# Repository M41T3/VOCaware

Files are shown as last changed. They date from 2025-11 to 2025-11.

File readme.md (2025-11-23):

# What is VOCaware?

VOCaware is a small device that measures volatile organic components (VOCs) in the ambient air and indicates potential unhealthy exposure.

VOCs are released during 3D printing caused by the melting process of plastic filaments. The exposure depends on the material and the melting temperature. Since there are no long term studies on the implications of VOC exposure to the human being it‘s reasonable to mitigate the risk of  potential health issues by avoiding these gases.

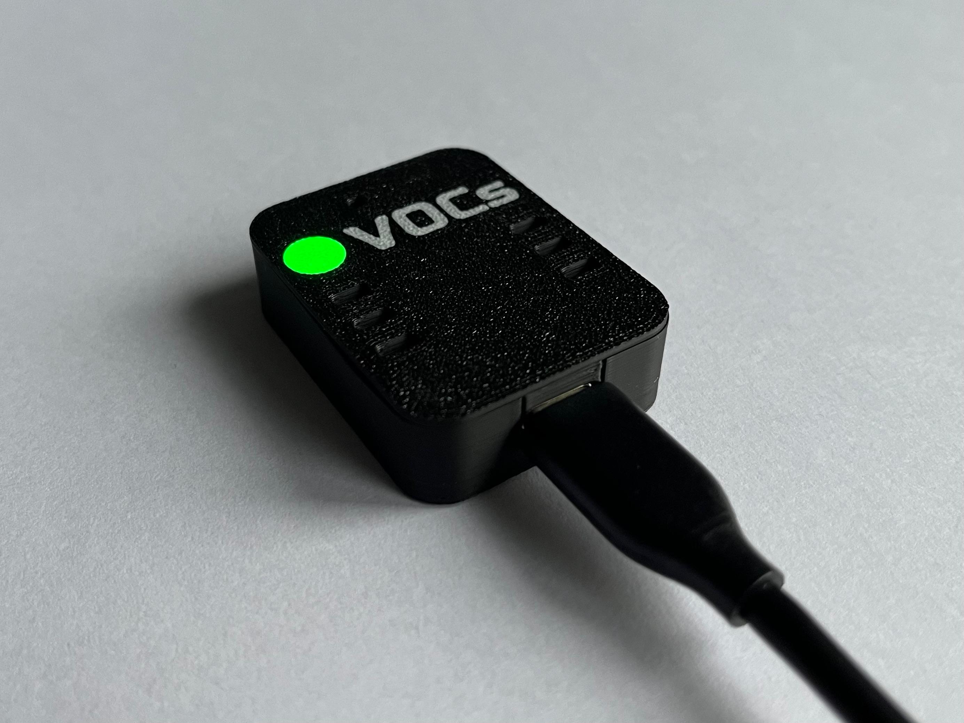
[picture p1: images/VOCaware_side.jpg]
VOCaware side view
  

# Features

- WIFI enabled microcontroller (ESP32-S3) to transmit sensor data wirelessly or via serial communication
- Sensirion SGP40 VOC sensor 
- Sensirion SHT40 temperature and humdity sensor to calibrate VOC sensor
- WS2812B LED to indicate intensity of exposure
- USB C plug to power and program device
- Compact PCB design (40 mm x 30 mm)
- Compact housing ( 43 mm x 33 mm x 11 mm) with magnets to easily attach to metal objects

# PCB

- 2 layers
- 40 x 30 mm
- JLCPCB production files available

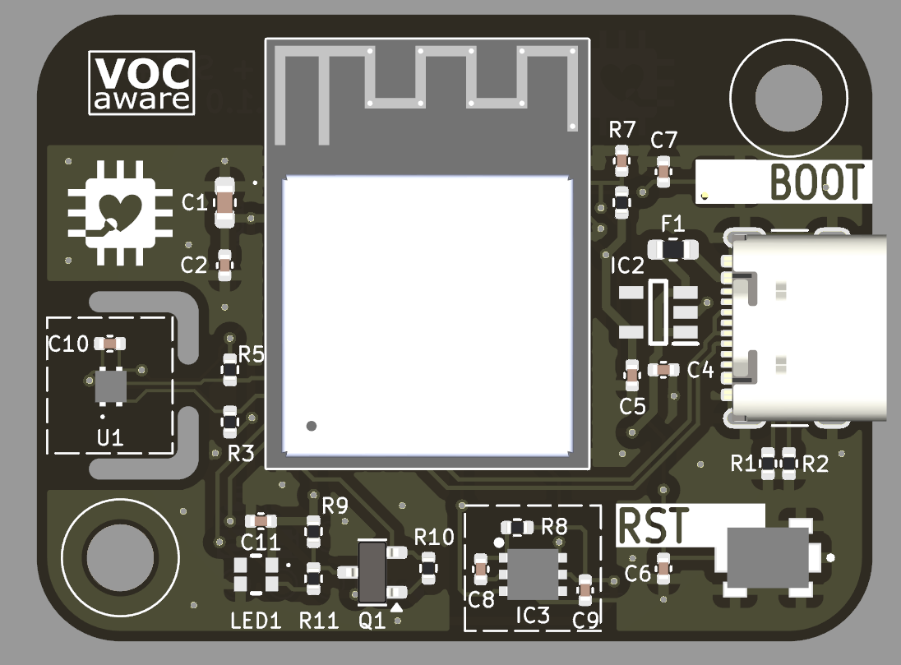
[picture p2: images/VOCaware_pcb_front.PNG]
VOCaware PCB front

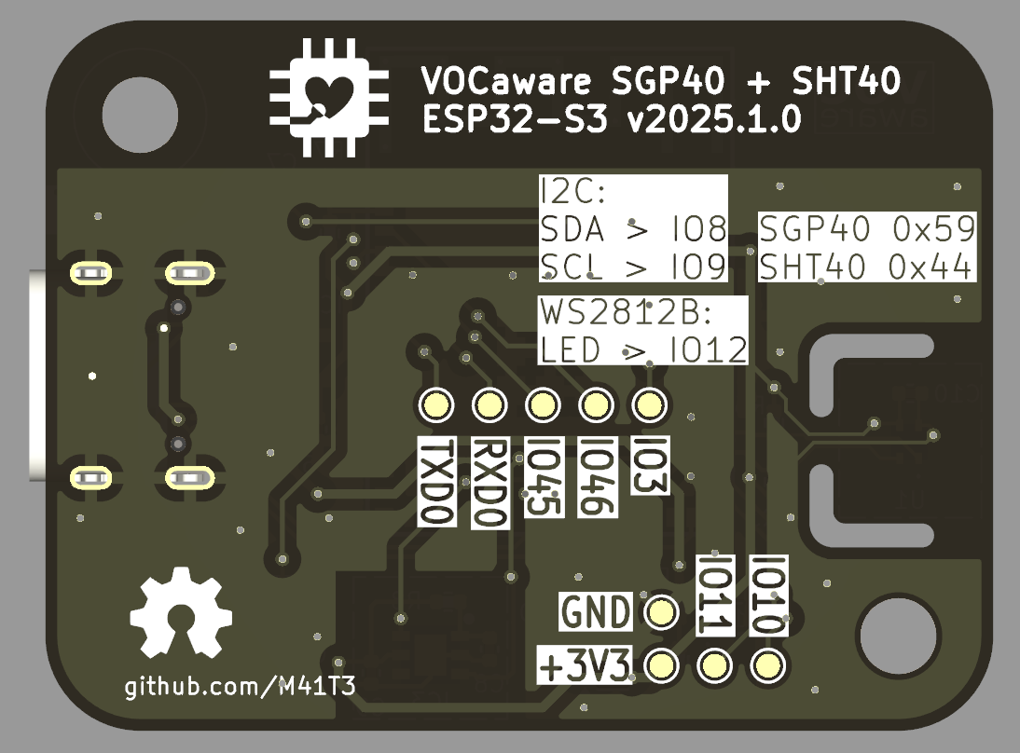
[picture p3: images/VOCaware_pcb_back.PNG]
VOCaware PCB front


# Housing

The lid simply clips to the bottom part of the housing. On the backside are holes for magnets.

Frontside:
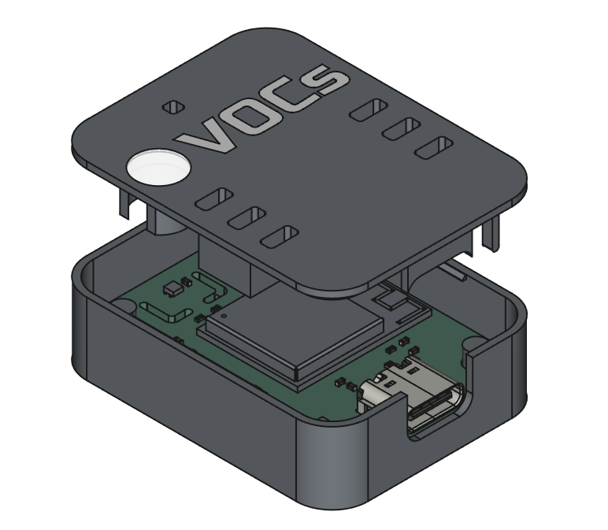
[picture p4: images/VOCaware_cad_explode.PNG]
VOCaware CAD1


Backside: 
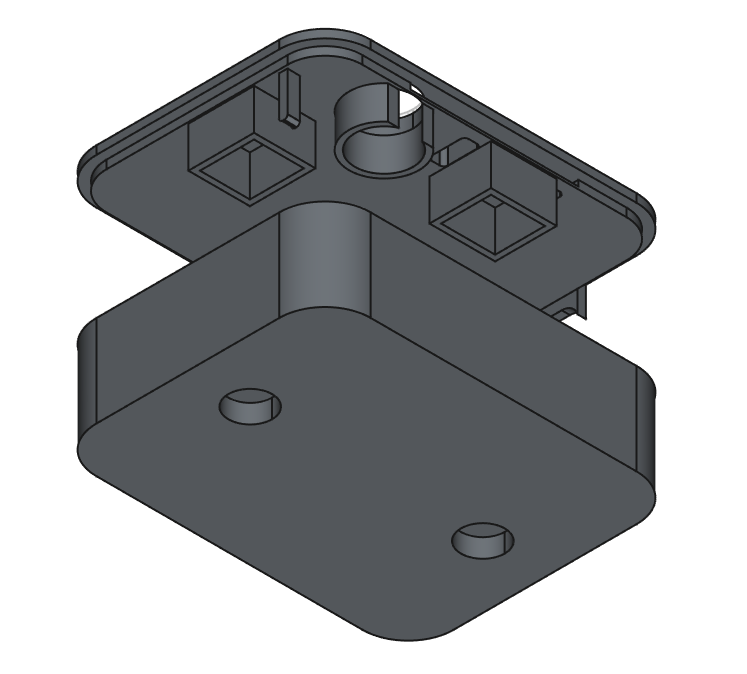
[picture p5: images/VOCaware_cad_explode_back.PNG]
VOCaware CAD2


# VOC Indication

Color code of the RGB LED is programmed according to Sensirions SGP40 VOC index scale to show a trend of the intensity over time. The devices needs severeal seconds to set up. During this, the LED blinks green.  

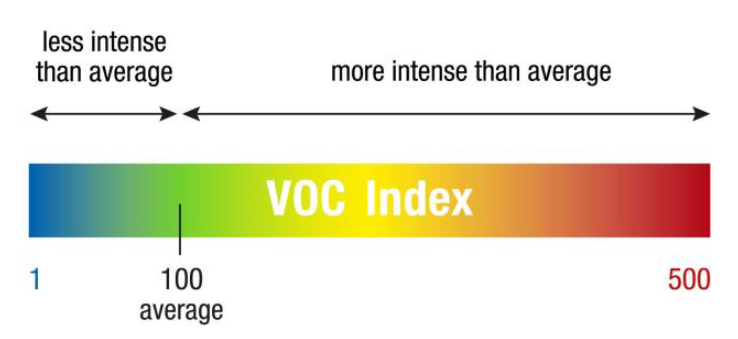
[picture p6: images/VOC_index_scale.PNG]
VOC Index Scale


| LED Color| VOC Index | Exposure |
|---|---|---|
| blue | 0 - 70  | decreased |
| green | 70 - 140 | OK |
| yellow | 131 - 210 | slightly increased |
| orange | 221 - 280 | increased |
| red | 281 - 350 | significantly increased |
| red blink  | 351 - 500 | concerningly increased  |

# Compatible to Bambu Lab P1S 3D Printer

Device fits in enclosure of the P1S printer and can be power directly from the internal USB plug. Please print the housing with PETG filament or similar so that it withstands the increased temperatures in the chamber.

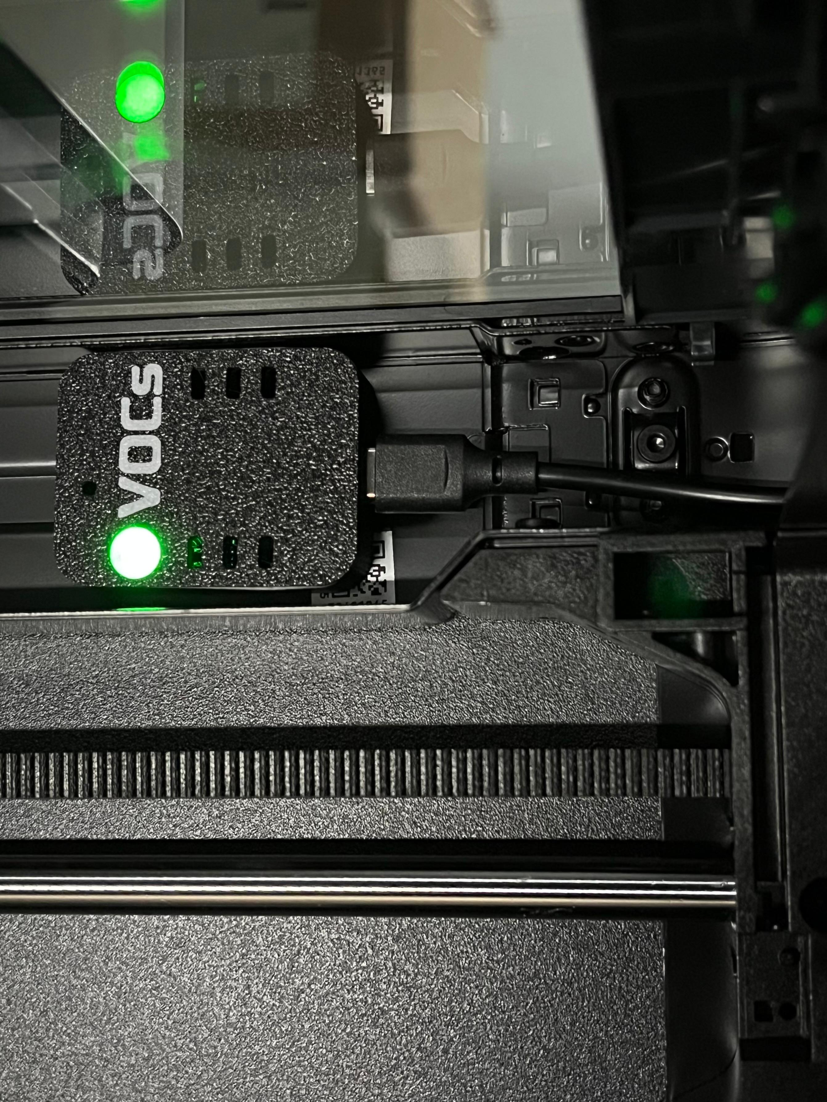
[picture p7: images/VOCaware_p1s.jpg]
VOCaware P1S

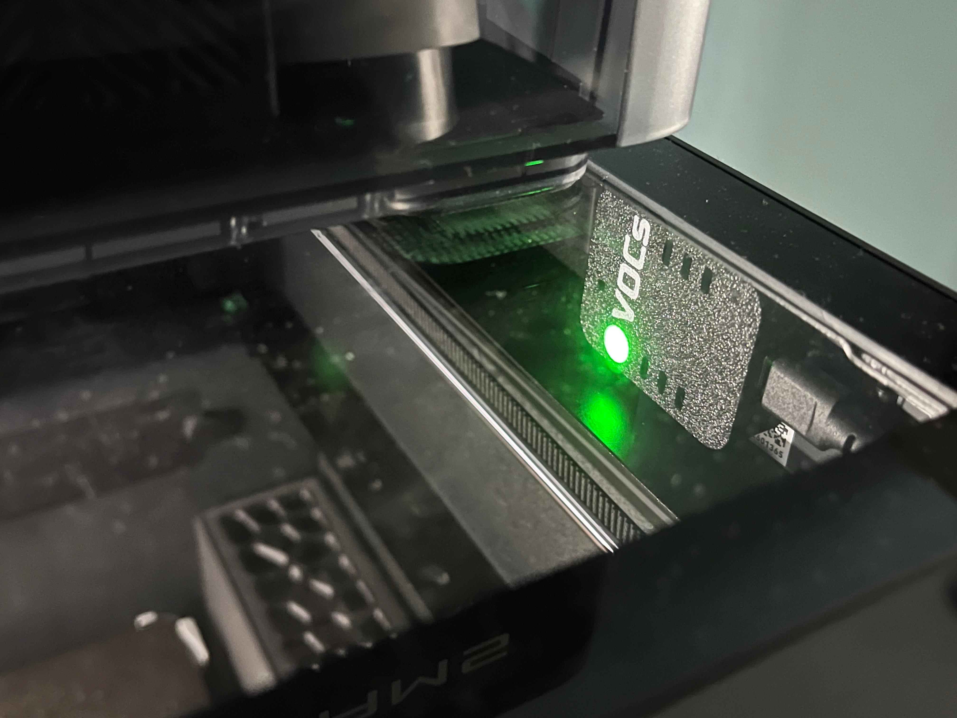
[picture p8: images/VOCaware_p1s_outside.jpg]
VOCaware P1S outside


The VOCaware is also visible in the camera view of the Bambu Studio interface:

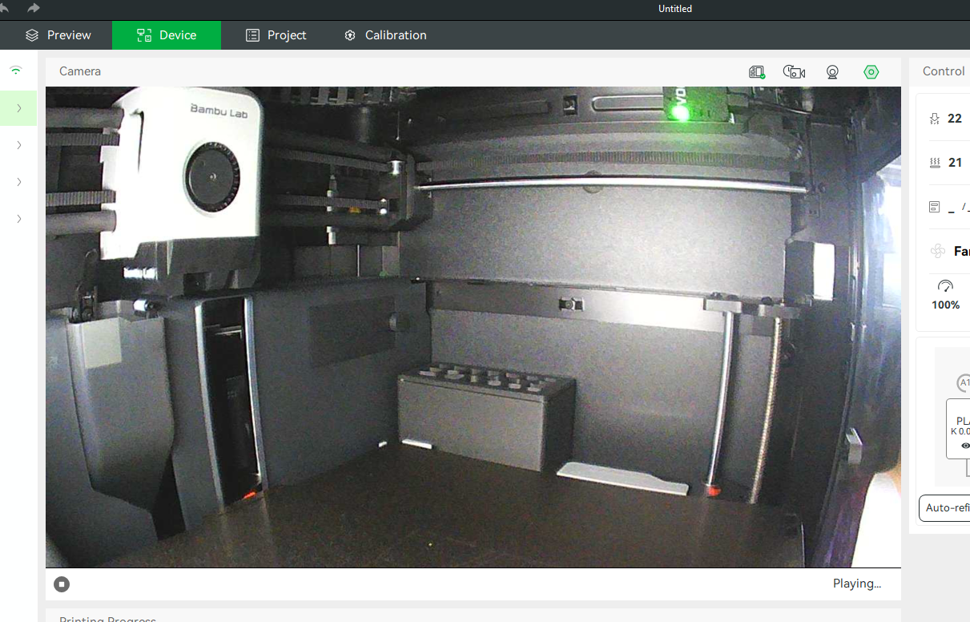
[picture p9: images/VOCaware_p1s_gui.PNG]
VOCaware P1S GUI


# What's Next
Ideas for improvements and features:

- Control Bento Box via VOCaware GPIO according to VOC Index
- Connect to MQTT Broker

# Known Issues

Unfortunatly the ground layer is not sufficiently interconnected. It can be easily fixed by soldering a short wire from the GND test pin to the ground zone as shown in the image:

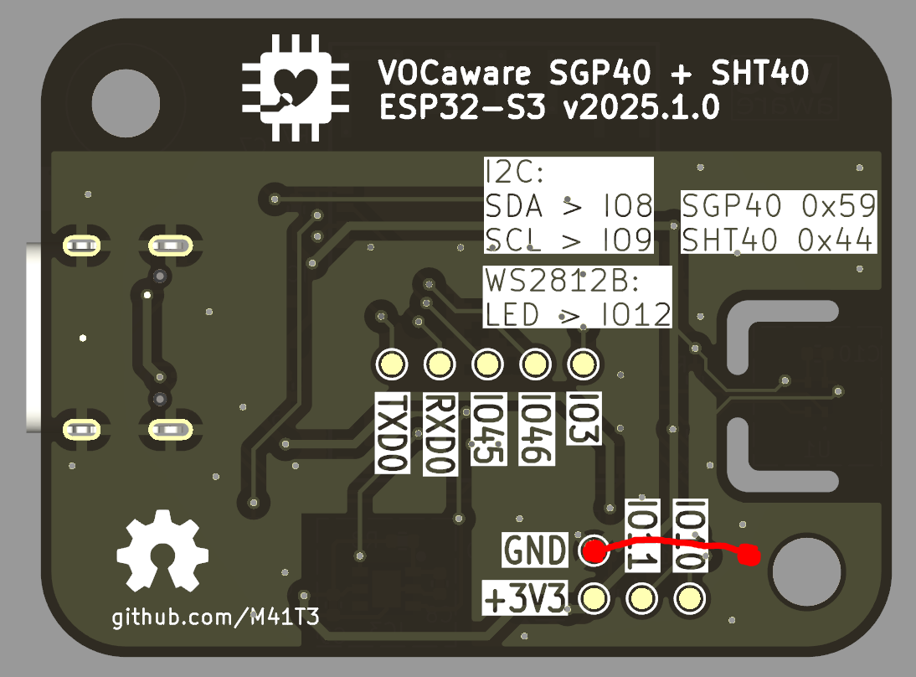
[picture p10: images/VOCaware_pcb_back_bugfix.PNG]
VOCaware ground layer


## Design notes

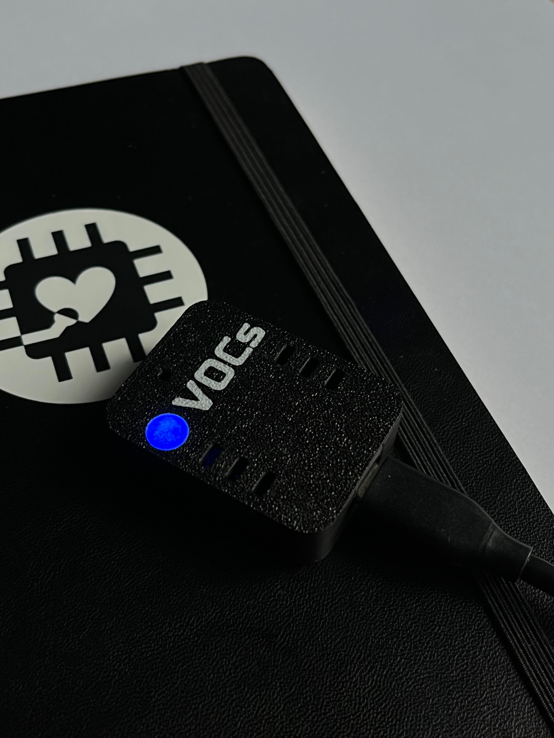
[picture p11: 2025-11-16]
images/VOCaware_blue.jpg

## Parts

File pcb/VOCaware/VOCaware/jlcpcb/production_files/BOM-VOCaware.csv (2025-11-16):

Comment | Designator | Footprint | LCSC | Quantity
BSS138BK | Q1 | SOT-23 | C112239 | 1
0.1uF | C10,C11,C2,C3,C6,C7 | C_0402_1005Metric | C1525 | 6
10uF | C4 | C_0402_1005Metric | C15525 | 1
USB_C_Receptacle_USB2.0_16P | J1 | USB_C_Receptacle_GCT_USB4105-xx-A_16P_TopMnt_Horizontal | C165948 | 1
SW_Push | SW1 | SolderJumper-2_P1.3mm_Open_Pad1.0x1.5mm | C221900 | 1
470 | R11 | R_0402_1005Metric | C25117 | 1
4.7 | R8 | R_0402_1005Metric | C25121 | 1
10k | R10,R7,R9 | R_0402_1005Metric | C25744 | 3
4.7k | R3,R5 | R_0402_1005Metric | C25900 | 2
5.1k 1% | R1,R2 | R_0402_1005Metric | C25905 | 2
SGP40-D-R4 | IC3 | SON80P244X244X95-7N | C2874215 | 1
ESP32-S3-MINI-1-N8 | IC1 | ESP32S3MINI1N8 | C2913206 | 1
XL-0807RGBC-WS2812B | LED1 | XL0807RGBCWS2812B | C3646929 | 1
AP2112K-3.3TRG1 | IC2 | SOT95P285X140-5N | C51118 | 1
1uF | C5,C8,C9 | C_0402_1005Metric | C52923 | 3
22uF | C1 | C_0603_1608Metric | C59461 | 1
SMD0603-050 | F1 | Fuse_0603_1608Metric | C69679 | 1
SHT40-AD1F-R2 | U1 | SHT40AD1FR2 | C7461846 | 1

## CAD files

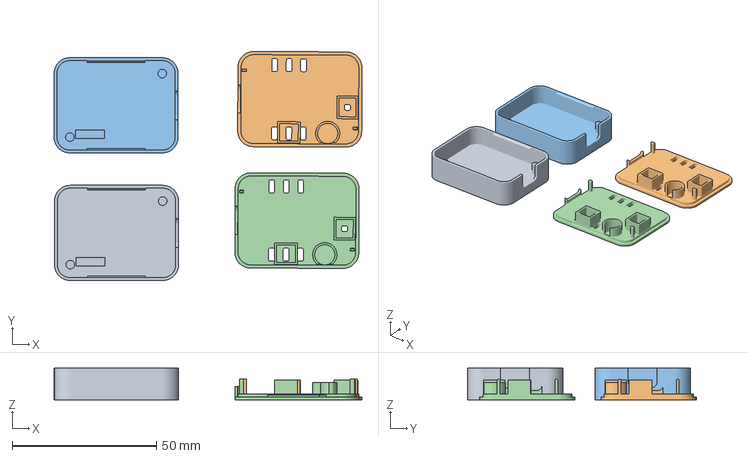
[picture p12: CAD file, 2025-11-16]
housing/VOCaware_housing_v1.3mf
106.7 x 79.3 x 11.0 mm
VOCaware_housing-housing_v1.step x 2
VOCaware_housing-lid_v1.step x 2

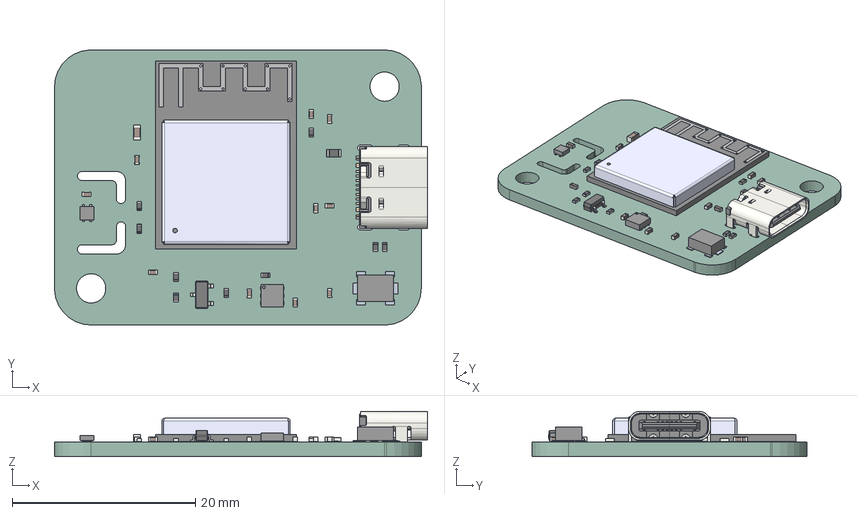
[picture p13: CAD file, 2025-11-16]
pcb/VOCaware/VOCaware/VOCaware.step
40.7 x 30.0 x 4.96 mm
C_0402_1005Metric x 10
R_0402_1005Metric x 9
SOT_23
ASSEMBLY x 3
C_0603_1608Metric
USB_C_Receptacle_16P_TopMnt_Horizontal_GCT_USB4105-xx-A
ESP32-S3-MINI-1-N8
Fuse_0603_1608Metric
VOCaware_PCB

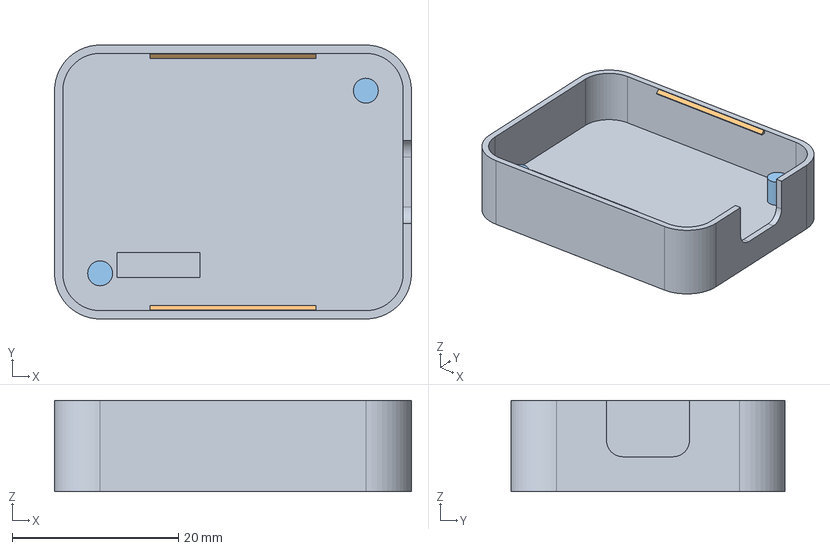
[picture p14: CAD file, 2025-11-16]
housing/VOCaware_housing-housing_v1.step
43.0 x 33.0 x 11.0 mm
housing_bottom
snap_bot_Chamfer
snap_top_Chamfer
m3_pole_tr
m3_pole_bl

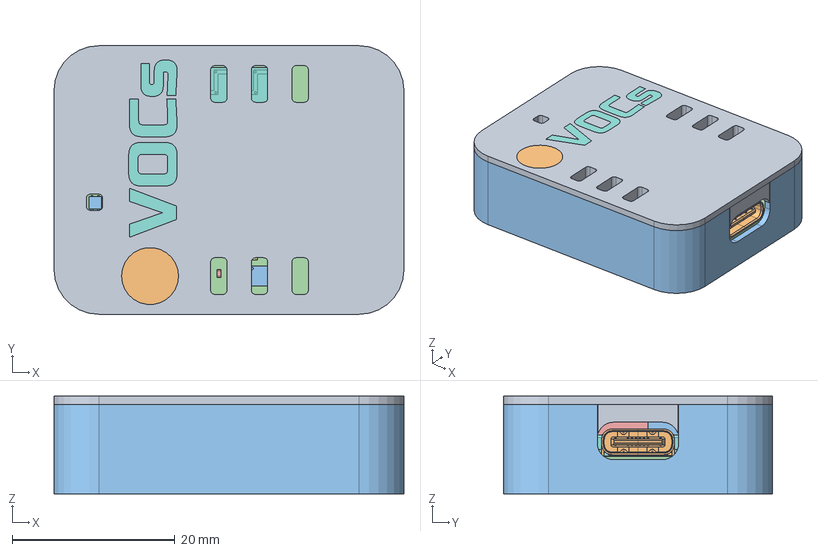
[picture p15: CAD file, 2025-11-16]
housing/VOCaware_housing.FCStd
43.0 x 33.0 x 12.0 mm
C_0402_1005Metric
C_0402_1005Metric002
R_0402_1005Metric
R_0402_1005Metric002
C_0402_1005Metric004
R_0402_1005Metric004
R_0402_1005Metric006
C_0402_1005Metric006
R_0402_1005Metric008
SOT_23
ASSEMBLY
R_0402_1005Metric010
C_0402_1005Metric008
C_0603_1608Metric
R_0402_1005Metric012
R_0402_1005Metric014
C_0402_1005Metric010
USB_C_Receptacle_16P_TopMnt_Horizontal_GCT_USB4105-xx-A
ASSEMBLY001
C_0402_1005Metric012
R_0402_1005Metric016
C_0402_1005Metric014
C_0402_1005Metric016
ESP32-S3-MINI-1-N8
C_0402_1005Metric018
Fuse_0603_1608Metric
ASSEMBLY002
VOCaware_PCB
m3_pole_bl
m3_pole_tr
snap_top_Chamfer
snap_bot_Chamfer
usb_top_cut
led_cirlcle_trans_extr
housing_bottom
sgp_separator_extr
sht_separator_extr
press_fit_tr_fillet
press_fit_bl_fillet
VOCs_text_extr_color
lid_text_cutout
led_sep_cutted

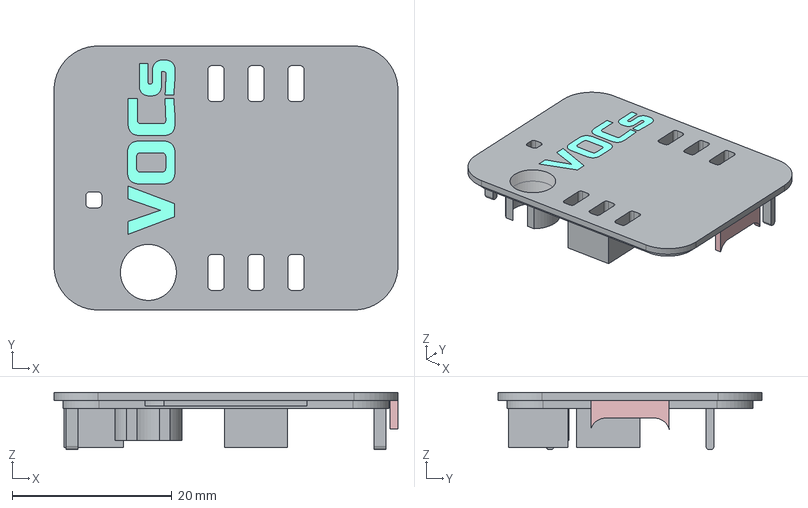
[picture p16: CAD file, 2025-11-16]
housing/VOCaware_housing-lid_v1.step
43.0 x 33.0 x 7.15 mm
led_sep_cutted
lid_text_cutout
VOCs_text_extr_color
press_fit_bl_fillet
press_fit_tr_fillet
sht_separator_extr
sgp_separator_extr
led_cirlcle_trans_extr
usb_top_cut

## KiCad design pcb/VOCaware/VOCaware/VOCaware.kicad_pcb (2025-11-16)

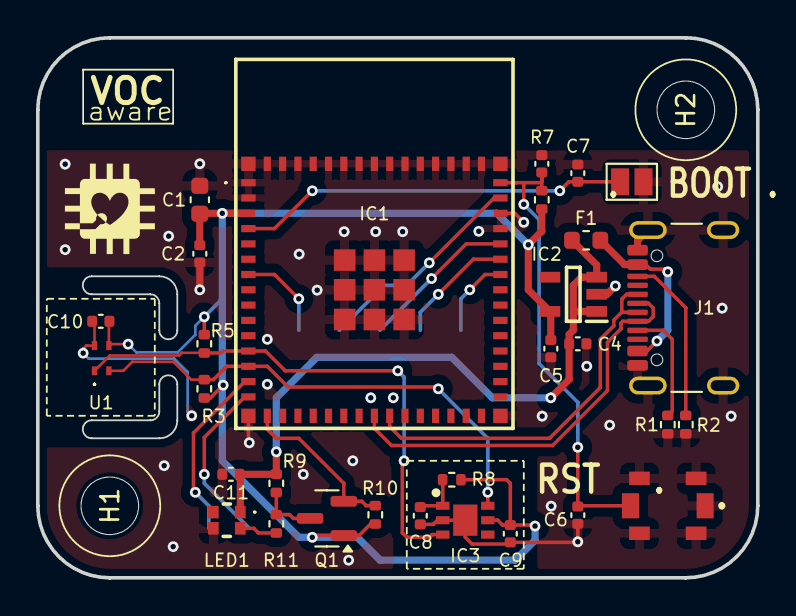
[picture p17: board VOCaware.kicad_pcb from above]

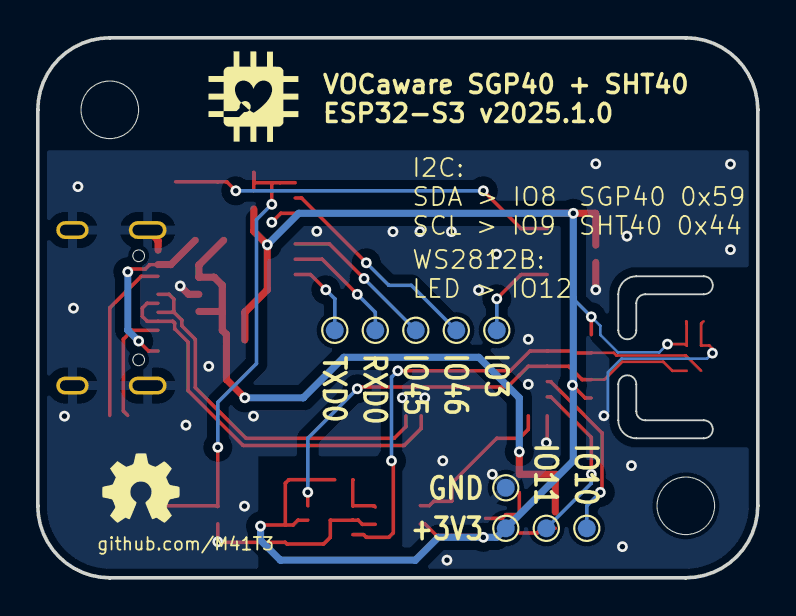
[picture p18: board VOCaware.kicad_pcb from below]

Board: 2 copper layers, 40.0 x 30.0 mm, 41 parts (9 on the bottom side), 23 nets.

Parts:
+3V3: Conn_01x01_Socket; TestPoint_Pad_D1.0mm
C1: 22uF; C_0603_1608Metric
C2, C3, C6, C7, C10, C11: 0.1uF; C_0402_1005Metric
C4: 10uF; C_0402_1005Metric
C5, C8, C9: 1uF; C_0402_1005Metric
F1: SMD0603-050; Fuse_0603_1608Metric
GND: Conn_01x01_Socket; TestPoint_Pad_D1.0mm
H1, H2: MountingHole; MountingHole_3.2mm_M3_DIN965
IC1: ESP32-S3-MINI-1-N8; ESP32S3MINI1N8
IC2: AP2112K-3.3TRG1; SOT95P285X140-5N
IC3: SGP40-D-R4; SON80P244X244X95-7N
IO3, IO10, IO11, IO45, IO46: Conn_01x01_Socket; TestPoint_Pad_D1.0mm
J1: USB_C_Receptacle_USB2.0_16P; USB_C_Receptacle_GCT_USB4105-xx-A_16P_TopMnt_Horizontal
LED1: XL-0807RGBC-WS2812B; XL0807RGBCWS2812B
Q1: BSS138BK; SOT-23
R1, R2: 5.1k 1%; R_0402_1005Metric
R3, R5: 4.7k; R_0402_1005Metric
R7, R9, R10: 10k; R_0402_1005Metric
R8: 4.7; R_0402_1005Metric
R11: 470; R_0402_1005Metric
RST   .: PTS820J25MSMTRLFS
RXD0: Conn_01x01_Socket; TestPoint_Pad_D1.0mm
SW1: SW_Push; SolderJumper-2_P1.3mm_Open_Pad1.0x1.5mm
TXD0: Conn_01x01_Socket; TestPoint_Pad_D1.0mm
U1: SHT40-AD1F-R2; SHT40AD1FR2

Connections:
+3V3: +3V3.1, C1.1, C2.1, C5.1, C9.1, C10.1, IC1.3 (3V3), IC2.5 (VOUT), IC3.5 (VDDH), Q1.1 (G), R3.1, R5.1, R7.1, R8.1, R10.1, U1.3 (VDD)
+5V: C4.1, C11.1, F1.1, IC2.1 (VIN), IC2.3 (EN), LED1.1 (VDD), R9.2
EN: C3.1, C6.1, IC1.45 (EN), R7.2, RST ..2 (N.O.)
GND: C1.2, C2.2, C3.2, C4.2, C5.2, C6.2, C7.2, C8.2, C9.2, C10.2, C11.2, GND.1, IC1.1 (GND_1), IC1.2 (GND_2), IC1.42 (GND_3), IC1.43 (GND_4), IC1.46 (GND_5), IC1.47 (GND_6), IC1.48 (GND_7), IC1.49 (GND_8), IC1.50 (GND_9), IC1.51 (GND_10), IC1.52 (GND_11), IC1.53 (GND_12), IC1.54 (GND_13), IC1.55 (GND_14), IC1.56 (GND_15), IC1.57 (GND_16), IC1.58 (GND_17), IC1.59 (GND_18), IC1.60 (GND_19), IC1.61 (GND_20), IC1.62 (GND_21), IC1.63 (GND_22), IC1.64 (GND_23), IC1.65 (GND_24), IC1.66 (GND_25), IC1.67 (GND_26), IC1.68 (GND_27), IC1.69 (GND_28), IC1.70 (GND_29), IC1.71 (GND_30), IC1.72 (GND_31), IC1.73 (GND_32), IC2.2 (GND), IC3.2 (VSS), IC3.7 (EP), J1.A1 (GND), J1.A12 (GND), J1.B1 (GND), J1.B12 (GND), J1.S1 (SHIELD), LED1.3 (GND), R1.1, R2.1, RST ..1 (COM), RST ..G1 (GND_1), RST ..G2 (GND_2), RST ..G3 (GND_3), RST ..G4 (GND_4), SW1.1, U1.4 (VSS)
I045_S: IC1.41 (IO45), IO45.1
I046_S: IC1.44 (IO46), IO46.1
IO0: C7.1, IC1.4 (IO0), SW1.2
IO3_S: IC1.7 (IO3), IO3.1
IO8_SDA0: IC1.12 (IO8), IC3.3 (SDA), R5.2, U1.1 (SDA)
IO9_SCL0: IC1.13 (IO9), IC3.6 (SCL), R3.2, U1.2 (SCL)
IO10: IC1.14 (IO10), IO10.1
IO11: IC1.15 (IO11), IO11.1
IO12: IC1.16 (IO12), Q1.2 (S), R10.2
LED_SIG: Q1.3 (D), R9.1, R11.1
unnamed: F1.2, J1.A4 (VBUS), J1.A9 (VBUS), J1.B4 (VBUS), J1.B9 (VBUS)
unnamed: C8.1, IC3.1 (VDD), R8.2
unnamed: J1.A5 (CC1), R1.2
unnamed: J1.B5 (CC2), R2.2
unnamed: LED1.4 (DIN), R11.2
RXD0: IC1.40 (RXD0), RXD0.1
TXD0: IC1.39 (TXD0), TXD0.1
USB_D+: IC1.24 (IO20), J1.A6 (D+), J1.B6 (D+)
USB_D-: IC1.23 (IO19), J1.A7 (D-), J1.B7 (D-)

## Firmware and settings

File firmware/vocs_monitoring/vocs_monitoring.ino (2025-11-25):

#include <FastLED.h>
#include "Adafruit_SGP40.h"
#include "Adafruit_SHT4x.h"

// LED constraints
#define LED_PIN 12
CRGB leds[1]; // GRB

// Sensirion SHT40 Temperature and Humidity Sensor
Adafruit_SHT4x sht4 = Adafruit_SHT4x();
sensors_event_t humidity, temp;

// Sensirion VOC Sensor
Adafruit_SGP40 sgp;
uint16_t sraw;
int32_t voc_index;

// Utils
#define INTERVAL 1000 // [ms] 
uint32_t timestamp;
bool blink_flag = 0;

void setup() {  

  Serial.begin(115200);

  // Initialize LED
  FastLED.addLeds<WS2812B, LED_PIN, RGB>(leds, 1);

  // Initialize VOC sensor
  if (! sgp.begin()){
    Serial.println("SGP40 sensor not found :(");
    while (1);
  }

  // Initialize temperature sensor
  if (! sht4.begin()) {
    Serial.println("Couldn't find SHT4x");
    while (1) delay(1);
  }

  sht4.setPrecision(SHT4X_HIGH_PRECISION); 
  sht4.setHeater(SHT4X_NO_HEATER);

  // LED Check
  leds[0] = 0xAA0000;
  FastLED.show();
  delay(1000);

  leds[0] = 0x00AA00; 
  FastLED.show();
  delay(1000);

  leds[0] = 0x0000AA; 
  FastLED.show();
  delay(1000);

  leds[0] = 0x000000; 
  FastLED.show();

}

void loop() {

  // Measure humidity, temperature and voc after specifed interval
  if (millis() - timestamp > INTERVAL){

    sht4.getEvent(&humidity, &temp);

    Serial.print("Temperature: "); Serial.print(temp.temperature); Serial.println(" degrees C");
    Serial.print("Humidity: "); Serial.print(humidity.relative_humidity); Serial.println("% rH");

    sraw = sgp.measureRaw(temp.temperature, humidity.relative_humidity);
    Serial.print("Raw measurement: "); Serial.println(sraw);

    voc_index = sgp.measureVocIndex(temp.temperature, humidity.relative_humidity);
    Serial.print("Voc Index: "); Serial.println(voc_index);

    timestamp = millis();

    // Change color of LED according to VOC index scale 
    if (voc_index == 0){
      if(blink_flag){
        leds[0] = 0x880000; //GRB
        blink_flag = 0;
      }else{
        leds[0] = 0x000000;
        blink_flag = 1;
      }
    }else if(voc_index < 70){
        leds[0] = 0x000055;
    }else if(voc_index < 140){
        leds[0] = 0x880000;
    }else if(voc_index < 210){
        leds[0] = 0x888800;
    }else if(voc_index < 280){
        leds[0] = 0x338800;
    }else if(voc_index < 350){
        leds[0] = 0x00AA00;
    }else{
      if(blink_flag){
        leds[0] = 0x00AA00; //GRB
        blink_flag = 0;
      }else{
        leds[0] = 0x000000;
        blink_flag = 1;
      }
    }
  }
  FastLED.show();
}
  
